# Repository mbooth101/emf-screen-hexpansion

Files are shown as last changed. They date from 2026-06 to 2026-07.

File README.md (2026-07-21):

# Screen Hexpansion

More screens is more better. Plug-in an auxialliary screen or two to maximise the amount of data you can display at a time! Or use them to create a multiocular Tildagon, just like everyone's favourite unicode glyph, the [multiocular O](https://en.wikipedia.org/wiki/Cyrillic_O_variants#Multiocular_O) "ꙮ".

## Firmware Install/Update

### Over-The-Air

You can initialise (and subsequently update) the Screen Hexpansion's firmware using the Tildagon badge's built-in "Hexpansions" app. Select the port it's plugged into and enter the VID `0x4D42` and PID `0x5EE5` to get the correct firmware.

### Manually

If you need to manually re-flash the Hexpansion firmware for any reason, or you want to install custom firmware, you can do so by inserting the Screen Hexpansion into port 2 of your Tildagon, and running the following commands:

```
cd emf-screen-hexpansion
mpremote mount EEPROM + run EEPROM/prepare_eeprom.py + cp EEPROM/app.py :/hexpansion/app.py
```

Once complete, the Screen Hexpansion may be inserted into any port. The script is just hard-coded to port 2 for flashing the firmware.

## License

This repo is MIT licensed and CERN Open Hardware licensed.

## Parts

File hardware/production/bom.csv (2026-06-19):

Designator | Footprint | Quantity | Value | LCSC Part #
R1, R2 | 603 | 2 | 4.7kΩ
U2 | SOIC-8_3.9x4.9mm_P1.27mm | 1 | AT24C256C-SSHL-T

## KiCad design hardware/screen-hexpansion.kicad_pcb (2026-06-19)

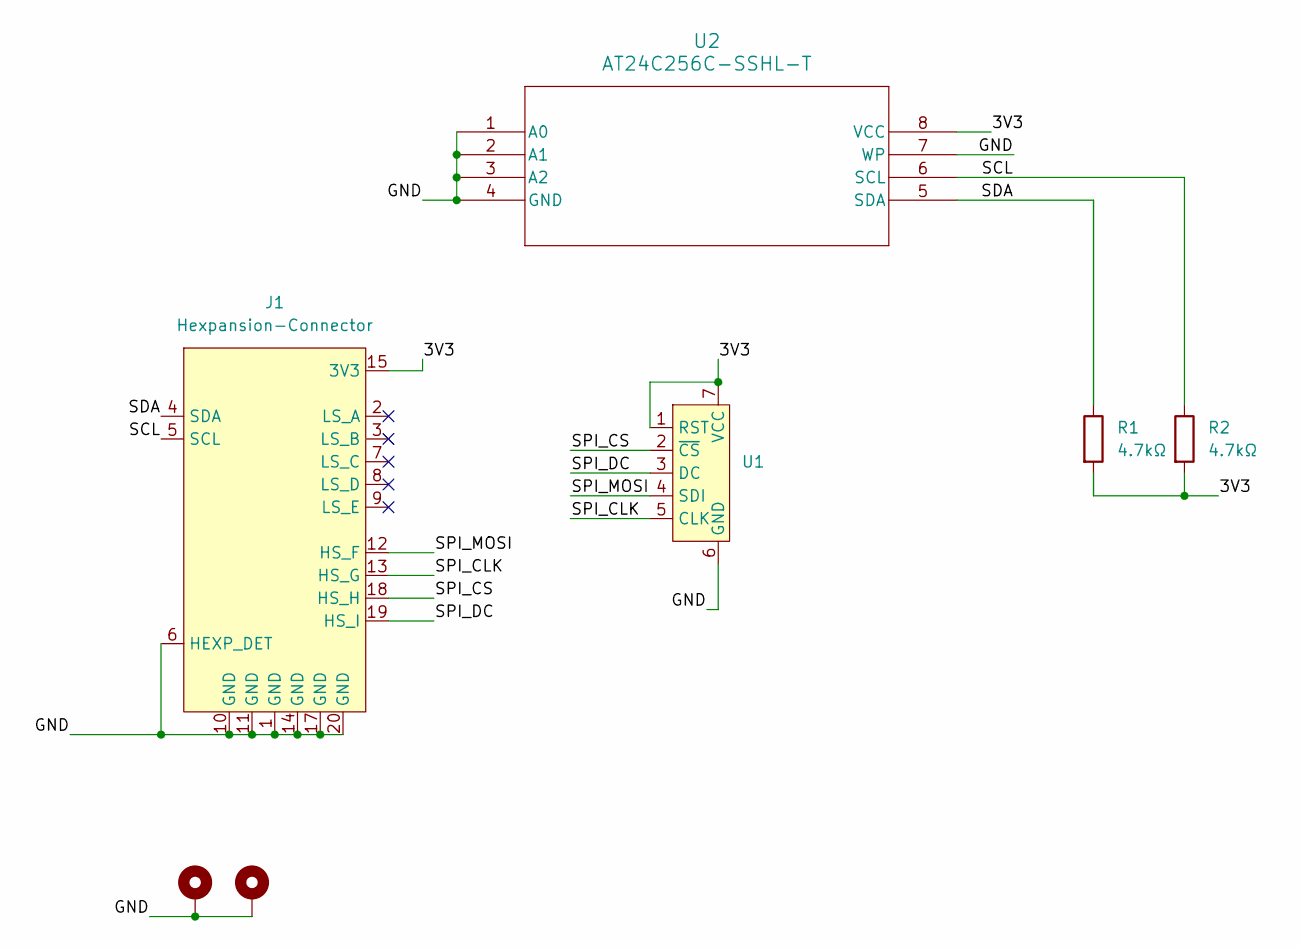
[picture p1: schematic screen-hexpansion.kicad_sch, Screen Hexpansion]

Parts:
H1, H2: MountingHole_Pad; MountingHole_2.2mm_M2_Pad_Via
J1: Hexpansion-Connector; hexpansion-edge-connector
R1, R2: 4.7kΩ; R_0603_1608Metric
U1: PinHeader_1x07_P2.54mm_Vertical_LockPads
U2: AT24C256C-SSHL-T; SOIC-8_3.9x4.9mm_P1.27mm

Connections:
/3V3: J1.15 (3V3), J1.16 (3V3), R1.2, R2.2, U1.1 (RST), U1.7 (VCC), U2.8 (VCC)
/GND: H1.1, H2.1, J1.1 (GND), J1.6 (HEXP_DET), J1.10 (GND), J1.11 (GND), J1.14 (GND), J1.17 (GND), J1.20 (GND), U1.6 (GND), U2.1 (A0), U2.2 (A1), U2.3 (A2), U2.4 (GND), U2.7 (WP)
/SCL: J1.5 (SCL), R2.1, U2.6 (SCL)
/SDA: J1.4 (SDA), R1.1, U2.5 (SDA)
/SPI_CLK: J1.13 (HS_G), U1.5 (CLK)
/SPI_CS: J1.18 (HS_H), U1.2 (~CS)
/SPI_DC: J1.19 (HS_I), U1.3 (DC)
/SPI_MOSI: J1.12 (HS_F), U1.4 (SDI)

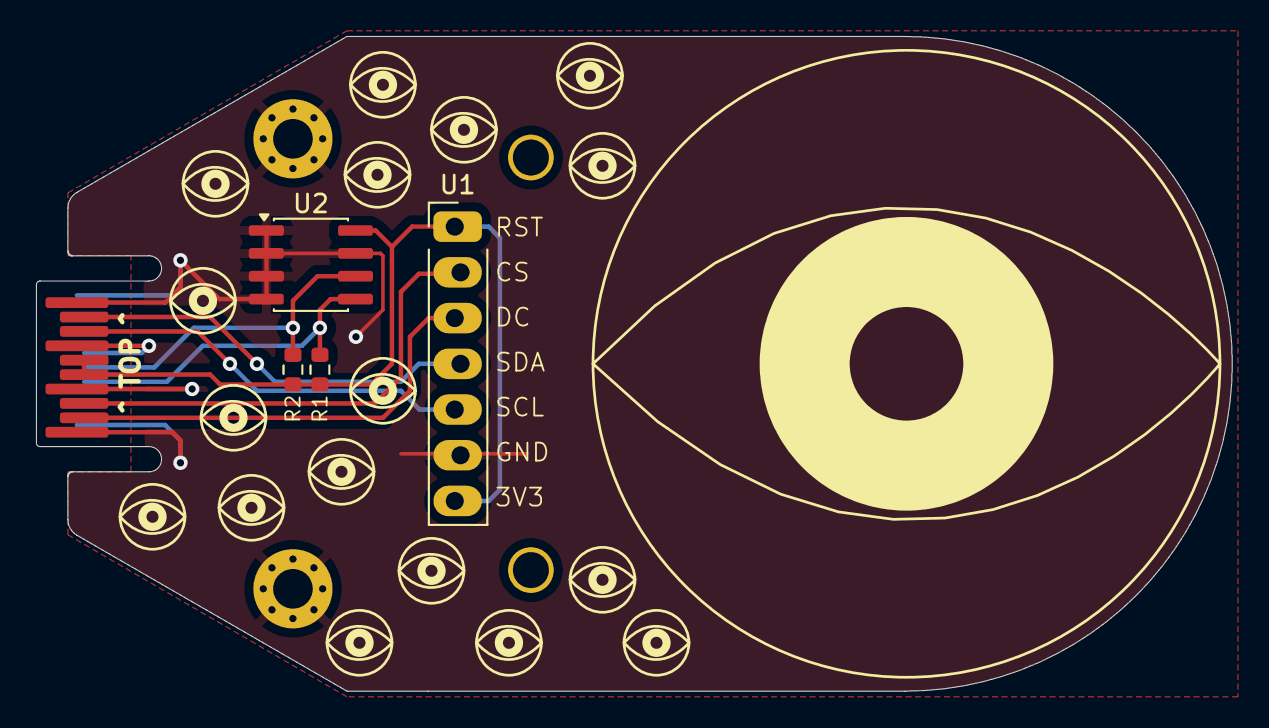
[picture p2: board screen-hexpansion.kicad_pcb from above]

Board: 2 copper layers, 66.4 x 36.4 mm, 7 parts (0 on the bottom side), 8 nets.

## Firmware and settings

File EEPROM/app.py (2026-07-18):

"""
Copyright (c) 2026 Mat Booth.

This file is part of the Screen Hexpansion for the Tildagon
(see https://github.com/mbooth101/emf-screen-hexpansion).

License: MIT
"""
import app
import math
import time

from ctx import Context, RGB565_BYTESWAPPED
from machine import SoftSPI, SPI, Pin

from system.eventbus import eventbus
from system.scheduler.events import RequestForegroundPushEvent

class AuxScreen(app.App):

    # Increment this when making changes to the app that require the hexpansion to be re-flashed with the new code.
    VERSION = 1

    # Screen dimension maximums
    WIDTH = 240
    HEIGHT = 240

    # Cargo culted commands to initialise the GC9A01, the meaning of some of
    # these can be found in the datasheet, but most are mysterious and stolen
    # from other GC9A01 driver implementations
    INIT_CMDS = [
        ( 0xef, ),
        ( 0xeb, [ 0x14 ] ),
        ( 0xfe, ),
        ( 0xef, ),
        ( 0xeb, [ 0x14 ] ),
        ( 0x84, [ 0x40 ] ),
        ( 0x85, [ 0xff ] ),
        ( 0x86, [ 0xff ] ),
        ( 0x87, [ 0xff ] ),
        ( 0x88, [ 0x0a ] ),
        ( 0x89, [ 0x21 ] ),
        ( 0x8a, [ 0x00 ] ),
        ( 0x8b, [ 0x80 ] ),
        ( 0x8c, [ 0x01 ] ),
        ( 0x8d, [ 0x01 ] ),
        ( 0x8e, [ 0xff ] ),
        ( 0x8f, [ 0xff ] ),
        ( 0xb6, [ 0x00, 0x20 ] ),
        ( 0x90, [ 0x08, 0x08, 0x08, 0x08 ] ),
        ( 0xbd, [ 0x06 ] ),
        ( 0xbc, [ 0x00 ] ),
        ( 0xff, [ 0x60, 0x01, 0x04 ] ),
        ( 0xC3, [ 0x13 ] ),
        ( 0xC4, [ 0x13 ] ),
        ( 0xC9, [ 0x22 ] ),
        ( 0xbe, [ 0x11 ] ),
        ( 0xe1, [ 0x10, 0x0e ] ),
        ( 0xdf, [ 0x21, 0x0c, 0x02 ] ),
        ( 0xf0, [ 0x45, 0x09, 0x08, 0x08, 0x26, 0x2a ] ),
        ( 0xf1, [ 0x43, 0x70, 0x72, 0x36, 0x37, 0x6f ] ),
        ( 0xf2, [ 0x45, 0x09, 0x08, 0x08, 0x26, 0x2a ] ),
        ( 0xf3, [ 0x43, 0x70, 0x72, 0x36, 0x37, 0x6f ] ),
        ( 0xed, [ 0x1b, 0x0b ] ),
        ( 0xae, [ 0x77 ] ),
        ( 0xcd, [ 0x63 ] ),
        ( 0x70, [ 0x07, 0x07, 0x04, 0x0e, 0x0f, 0x09, 0x07, 0x08, 0x03 ] ),
        ( 0xe8, [ 0x34 ] ),
        ( 0x62, [ 0x18, 0x0D, 0x71, 0xED, 0x70, 0x70, 0x18, 0x0F, 0x71, 0xEF, 0x70, 0x70 ] ),
        ( 0x63, [ 0x18, 0x11, 0x71, 0xF1, 0x70, 0x70, 0x18, 0x13, 0x71, 0xF3, 0x70, 0x70 ] ),
        ( 0x64, [ 0x28, 0x29, 0xF1, 0x01, 0xF1, 0x00, 0x07 ] ),
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
        ( 0x11, None, 150 ),
        ( 0x29, None, 150 ),
    ]

    def __init__(self, config=None):
        super().__init__()

        # Eye dimensions
        self.sclera_radius = 110
        self.iris_radius = 50
        self.pupil_radius = 20
        self.glint_radius = 4
        self.blink_ratio = 0.5

        self.elapsed = 0
        self.duration = 1000

        # Config is mandatory, we're running from the EEPROM
        if config is None:
            raise TypeError
        self.config = config

        # Data/command select pin
        self.dc = config.pin[3]
        self.dc.init(mode=Pin.OUT, pull=0)

        # Chip select pin
        # Always pull low, there's only one device on the bus
        self.cs = config.pin[2]
        self.cs.init(mode=Pin.OUT, pull=0, value=0)

        # Initialise the SPI bus
        self.spi = SPI(1, baudrate=40 * 1000 * 1000,
            sck=config.pin[1], mosi=config.pin[0], miso=config.pin[2])

        # Fire intialisation sequence at the display
        for init_cmd in AuxScreen.INIT_CMDS:
            self._write_cmd(init_cmd[0])
            if len(init_cmd) > 1 and init_cmd[1]:
                self._write_data(init_cmd[1])
            if len(init_cmd) > 2 and init_cmd[2]:
                time.sleep_ms(init_cmd[2])

        # Blit the full frame
        self._column_addr_set(0, AuxScreen.WIDTH - 1)
        self._row_addr_set(0, AuxScreen.HEIGHT - 1)

        # Allocate a frame buffer 16 bits per pixel
        self._fb = bytearray(AuxScreen.WIDTH * AuxScreen.HEIGHT * 2)

        # Create a CTX Context for the frame buffer
        self._ctx = Context(width=AuxScreen.WIDTH, height=AuxScreen.HEIGHT,
            stride=AuxScreen.WIDTH * 2, format=RGB565_BYTESWAPPED, buffer=self._fb)

        # Does it expose additional methods for animation?
        self.capable = hasattr(self._ctx, "identity")

        self.foregrounded = False
        self.drawn = False

    def _write_cmd(self, cmd):
        self.dc.off()
        self.spi.write(bytes([cmd]))

    def _write_data(self, data):
        self.dc.on()
        self.spi.write(bytes(data))

    def _column_addr_set(self, start, end):
        self._write_cmd(0x2A) # CASET(2Ah)
        self._write_data([start >> 8, start & 0xFF, end >> 8, end & 0xFF])

    def _row_addr_set(self, start, end):
        self._write_cmd(0x2B) # PASET(2Bh)
        self._write_data([start >> 8, start & 0xFF, end >> 8, end & 0xFF])

    def _blit(self):
        self._write_cmd(0x2C) # RAMWR(2Ch)
        self._write_data(self._fb)

    def get_ctx(self):
        """Starts the frame and returns the context"""
        self._ctx.save()

        # Reset to identity matrix, I think the tildagon OS driver does this
        # because it's not doing a proper CTX end_frame() call
        if self.capable:
            self._ctx.identity()

        # Move the origin to the centre of the screen
        offset_x = AuxScreen.WIDTH / 2
        offset_y = AuxScreen.HEIGHT / 2
        self._ctx.apply_transform(1.0, 0.0, offset_x, 0.0, 1.0, offset_y, 0.0, 0.0, 1.0)

        # Rotate according to which hexpansion port we're plugged into
        factor = self.config.port - 2
        self._ctx.rotate(math.pi / 2 - factor * math.pi / 3)

        return self._ctx

    def end_frame(self):
        """Blits to the screen and ends the frame"""
        self._ctx.restore()
        self._blit()

        # From the tildagon OS driver:
        # display.end_frame() cannot call ctx_end_frame() directly here: that resets
        # rasterizer state, including the framebuffer clip bounds, which leaves
        # subsequent frames blank. Advance only the texture eviction clock.
        if self.capable:
            self._ctx.set_textureclock(self._ctx.textureclock() + 1)
        
    def update(self, delta):
        ctx = self.get_ctx()
        self._draw_inner_eye(ctx)
        self._draw_eyelids(ctx)
        self.end_frame()

        # If the additional methods aren't present, then might as well exit
        if self.capable:
            self.minimise()
        else:
            self.terminate()

    def background_update(self, delta):
        if not self.capable:
            return

        self.elapsed += delta
        if self.elapsed >= self.duration:
            self.elapsed = self.elapsed - self.duration
        self.blink_ratio = self.curve(self.duration, self.elapsed)

        ctx = self.get_ctx()
        self._draw_inner_eye(ctx)
        self._draw_eyelids(ctx)
        self.end_frame()

    def curve(self, duration, elapsed):
        throb = math.sin(((math.pi * 2) / duration) * elapsed)
        return (throb + 1) * 0.5
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

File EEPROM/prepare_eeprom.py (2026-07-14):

# This file is based on scripts from the main badge-2024-software repo

from machine import I2C
from system.hexpansion.header import HexpansionHeader, write_header
from system.hexpansion.util import (
    detect_eeprom_addr,
    get_hexpansion_block_devices,
    read_hexpansion_header,
)
import vfs
import os
import sys


# Set up i2c
port = 2  # <<-- Customize!!
i2c = I2C(port)

# Detect eeprom address
addr, addr_len = detect_eeprom_addr(i2c)
print(f"Detected eeprom at {hex(addr)}")

header = HexpansionHeader(
    manifest_version="2024",
    fs_offset=64,
    eeprom_page_size=64,
    eeprom_total_size=32768,
    vid=0x4D42,
    pid=0x5EE5,
    unique_id=0,
    friendly_name="Screen",
)

# Write and read back header
write_header(
    port, header, addr=addr, addr_len=addr_len, page_size=header.eeprom_page_size
)
header = read_hexpansion_header(i2c, addr, set_read_addr=True, addr_len=addr_len)
if header is None:
    raise RuntimeError(f"Failed to read back hexpansion header for hexpansion {port}")

# Get block devices
try:
    eep, partition = get_hexpansion_block_devices(i2c, header, addr, addr_len=addr_len)
    vfs.VfsLfs2.mkfs(partition)
except Exception as e:
    raise RuntimeError(f"Failed to get block devices for hexpansion {port}: {e}")

mountpoint = f"/hexpansion"
try:
    vfs.mount(partition, mountpoint)
except Exception as e:
    raise RuntimeError(f"Failed to mount partition for hexpansion {port}: {e}")

print(f"Mounted hexpansion {port} at {mountpoint}")

# Remove any pre-existing files
files = os.listdir(mountpoint)
for f in files:
    os.remove(f"{mountpoint}/{f}")

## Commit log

2026-06-19 Initial commit of v1 Screen Hexpansion
    [screen-hexpansion.kicad_pcb, screen-hexpansion.kicad_sch]
2026-06-19 Add PCB production files
    [bom.csv, designators.csv, positions.csv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]
2026-07-17 Fix screen rotation according to the connected hexpansion port
    Detect when the firmware CTX object has the additional methods exposed,
    by testing if ctx.identity() is present
    [app.py]
